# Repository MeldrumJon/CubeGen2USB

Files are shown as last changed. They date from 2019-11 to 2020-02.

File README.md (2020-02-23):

# CubeGen2USB

GameCube and Sega Genesis to USB adapter.  Works for both XInput and DInput 
(depending on which Arduino sketch is used). Only one controller may be used at 
a time (if both controllers are plugged in, the GameCube controller is used).

Photo of the adapter

## Parts

- Arduino Micro
- 1x [DB9 Male Connector](https://www.mouser.com/ProductDetail/571-2301843-1)
- 1x GameCube controller extension cable, cut in half with wires stripped.
- 5x [SPDT Slide Switches](https://www.amazon.com/gp/product/B01M1CU2B0/)
- 1x [Bi-Direction 3.3V-5V Logic Level Converter Module](https://www.amazon.com/gp/product/B07F7W91LC/)
	- or 1x BSS138 MOSFET and 2x 10k resistors.
- Breakaway Headers

Be careful when soldering the GameCube extension cable wires onto the PCB.  Use 
[this](https://github.com/NicoHood/Nintendo/wiki/Gamecube#hardware) as a reference, 
but disregard the wire colors.  Use a continuity tester to determine which wire 
is connected to each pin.

## PCB

KiCAD files are in the [hardware](./hardware) folder.

Circuit Schematic

3rd-party KiCAD libaries used:

- [Arduino KiCAD Library](https://github.com/Alarm-Siren/arduino-kicad-library)

## Programming

### DInput Setup

#### Required Libraries

- [SegaController by Jon Thysell](https://github.com/jonthysell/SegaController)
- Nintendo by NicoHood
- HID-Project by NicoHood

### XInput Setup

#### Hardware Setup

1. Download
[XInput USB Core for Arduino AVR](https://github.com/dmadison/ArduinoXInput_AVR) 
and extract it to `Arduino/hardware/xinput/avr`.
1. Change the board in Arduino IDE to "Arduino Micro w/ XInput".
1. Burn the bootloader using an In-circuit Serial Programmer ([Another Arduino 
can be used as an ISP](https://www.arduino.cc/en/tutorial/arduinoISP)).

Once the bootloader is burned, you will have to press the reset button when 
uploading sketches or simply upload using the ISP.

#### Required Libraries

- [SegaController by Jon Thysell](https://github.com/jonthysell/SegaController)
- Nintendo by NicoHood
- XInput by David Madison

## Features

The five switches can be used to control how buttons are mapped to the emulated 
XBox 360 controller. By default:

| XBox | GameCube | Genesis |
| --- | --- | --- |
| Start | Start | Start |
| A | A | A |
| B | B | B |
| X | X | X |
| Y | Y | Y |
| L Bumper | L Trigger Button | C |
| R Bumper | R Trigger Button | Mode |

- SW1: Swap A&B, X&Y
- SW2: Z maps to R Bumper
- SW3: 
- SW4: 
- SW5:

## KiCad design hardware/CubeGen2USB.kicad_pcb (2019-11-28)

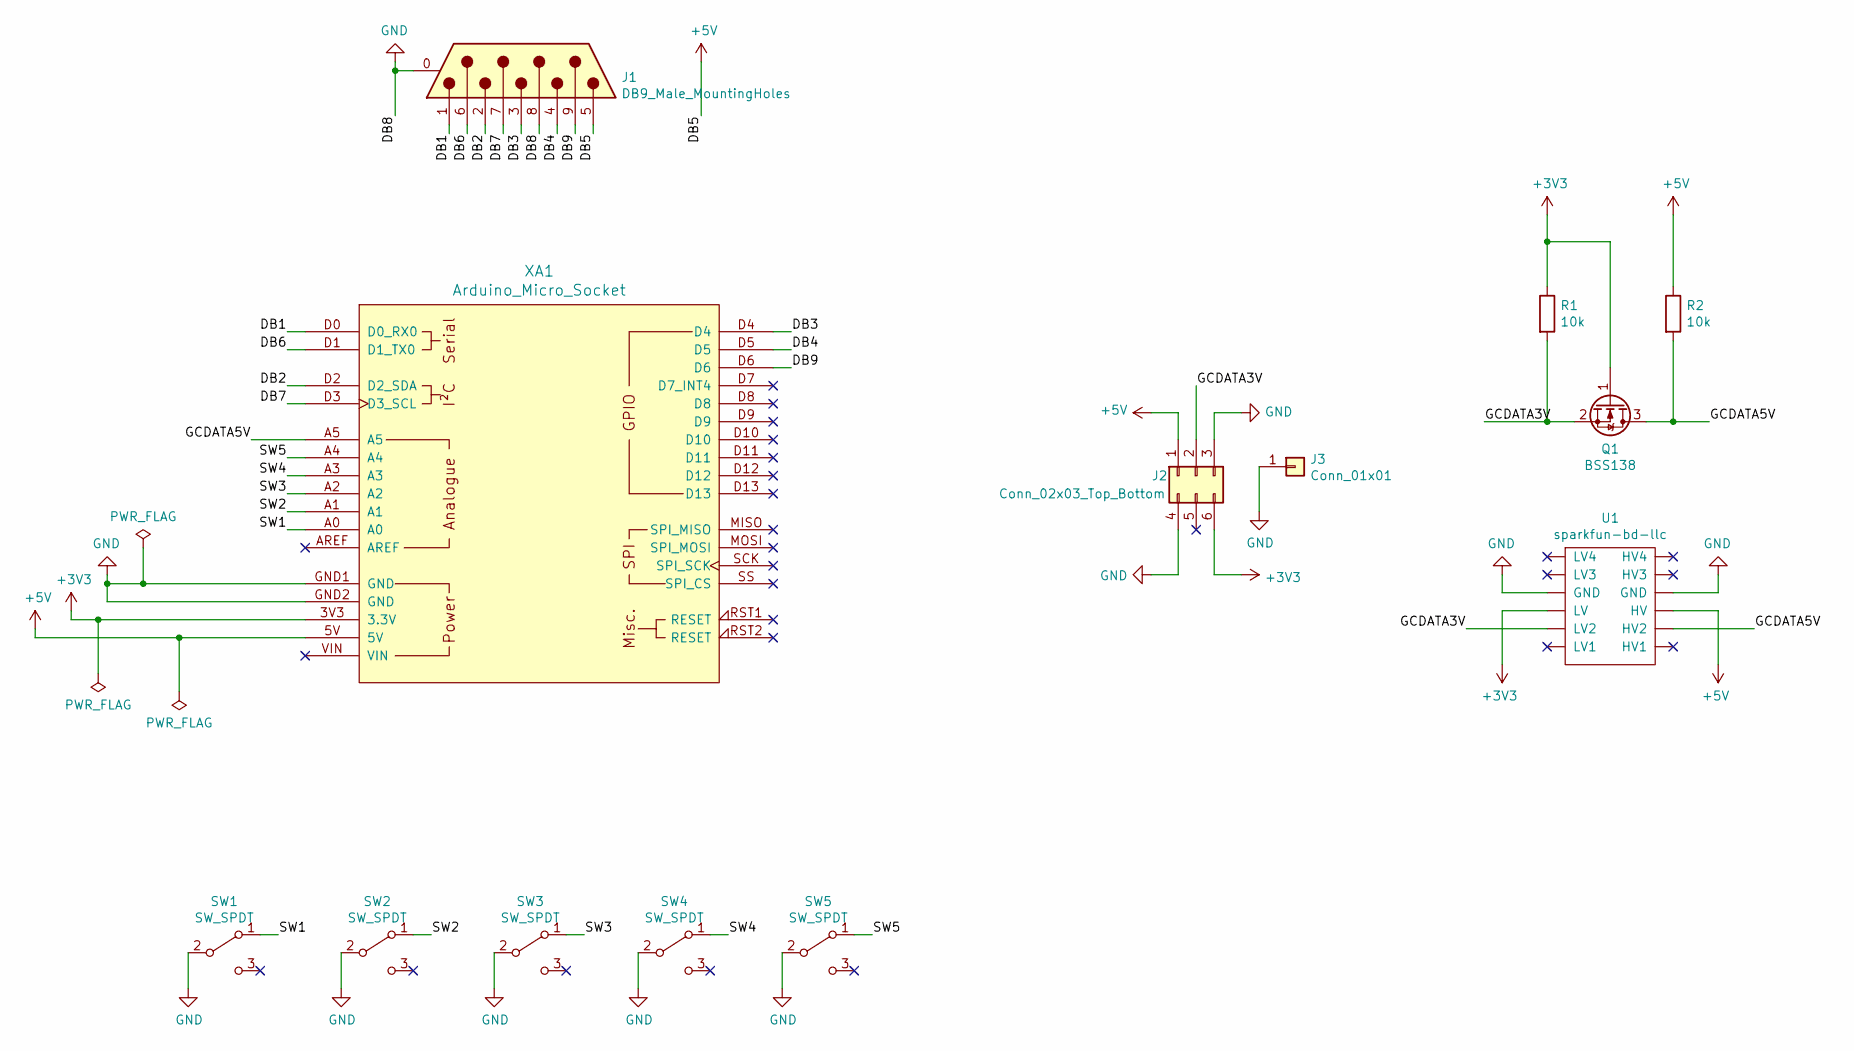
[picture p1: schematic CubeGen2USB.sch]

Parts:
J1: DB9_Male_MountingHoles; DB9-2301843-1
J2: Conn_02x03_Top_Bottom; PinSocket_2x03_P2.54mm_Vertical
J3: Conn_01x01; PinSocket_1x01_P2.54mm_Vertical
Q1: BSS138; SOT-23_Handsoldering
R1, R2: 10k; R_Axial_DIN0207_L6.3mm_D2.5mm_P2.54mm_Vertical
SW1, SW2, SW3, SW4, SW5: SW_SPDT; SPDT_THT_Slide_SW
U1: sparkfun-bd-llc
XA1: Arduino_Micro_Socket; Arduino_Micro_Socket_noHoles

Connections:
+3V3: J2.6, Q1.1 (G), R1.1, U1.LV, XA1.3V3 (3.3V)
+5V: J1.5, J2.1, R2.1, U1.HV, XA1.5V
/DB1: J1.1, XA1.D0 (D0_RX0)
/DB2: J1.2, XA1.D2 (D2_SDA)
/DB3: J1.3, XA1.D4
/DB4: J1.4, XA1.D5
/DB6: J1.6, XA1.D1 (D1_TX0)
/DB7: J1.7, XA1.D3 (D3_SCL)
/DB9: J1.9, XA1.D6
/GCDATA3V: J2.2, Q1.2 (S), R1.2, U1.LV2
/GCDATA5V: Q1.3 (D), R2.2, U1.HV2, XA1.A5
/SW1: SW1.1 (A), XA1.A0
/SW2: SW2.1 (A), XA1.A1
/SW3: SW3.1 (A), XA1.A2
/SW4: SW4.1 (A), XA1.A3
/SW5: SW5.1 (A), XA1.A4
GND: J1.0 (PAD), J1.8, J2.3, J2.4, J3.1, SW1.2 (B), SW2.2 (B), SW3.2 (B), SW4.2 (B), SW5.2 (B), U1.GNDH (GND), U1.GNDL (GND), XA1.GND1 (GND), XA1.GND2 (GND)

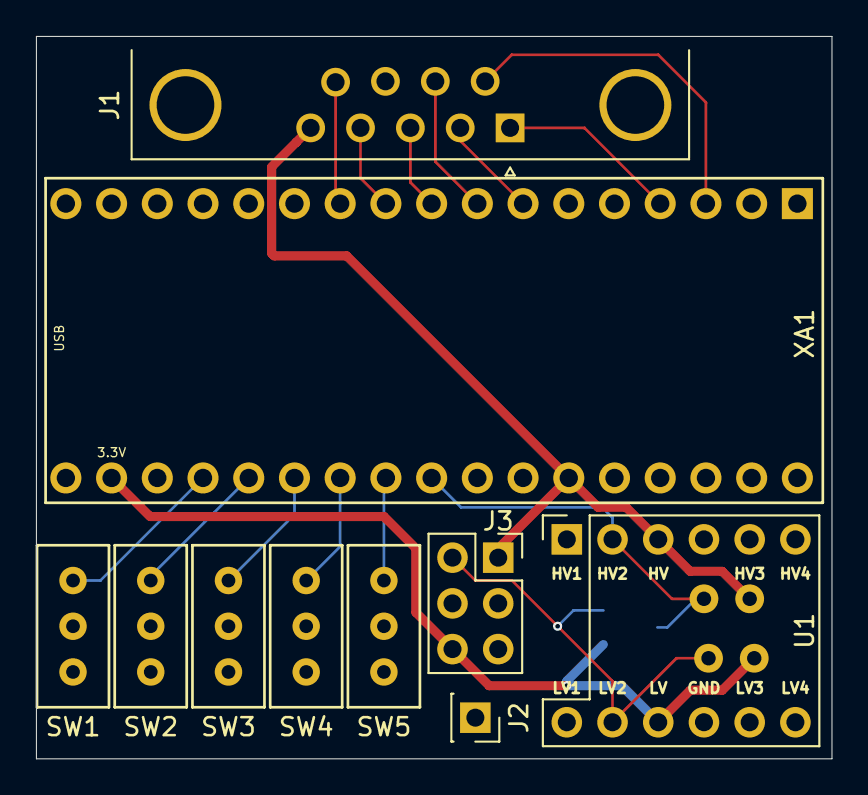
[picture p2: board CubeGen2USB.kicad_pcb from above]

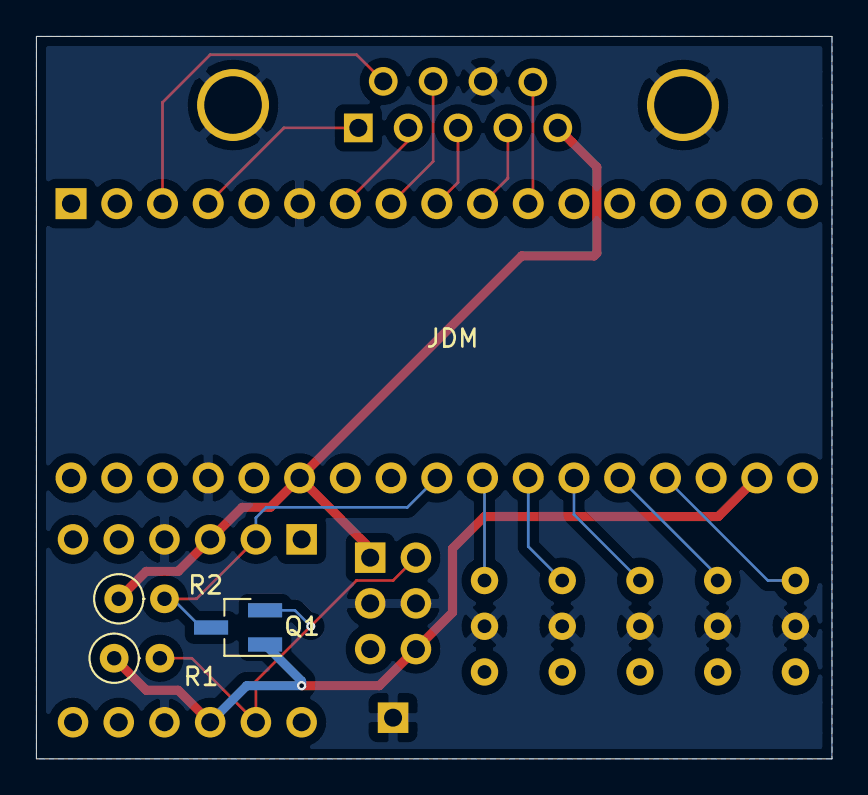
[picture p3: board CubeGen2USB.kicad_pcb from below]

Board: 2 copper layers, 44.2 x 40.1 mm, 13 parts (3 on the bottom side), 17 nets.

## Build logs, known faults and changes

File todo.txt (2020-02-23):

- Find a way to toggle between XInput and DInput with a switch.

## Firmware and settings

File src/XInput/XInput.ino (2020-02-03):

#include <SegaController.h>
#include <Nintendo.h>
#include <XInput.h>

// Micro Pins: 3, 0, 2, 4, 5, 1, 6 
// DB9 Pins:   7, 1, 2, 3, 4, 6, 9
SegaController sgController(3, 0, 2, 4, 5, 1, 6);
CGamecubeController gcController(A5); // 5V GC Data

#define SW1 0x01
#define SW2 0x02
#define SW3 0x04
#define SW4 0x08
#define SW5 0x10

static int readSwitches() {
    int val = 0;
    if (digitalRead(A0)) { val |= SW1; }
    if (digitalRead(A1)) { val |= SW2; }
    if (digitalRead(A2)) { val |= SW3; }
    if (digitalRead(A3)) { val |= SW4; }
    if (digitalRead(A4)) { val |= SW5; }
    return ~(val);
}

static int switches = 0;

static void sendGen(word state) {
  static word lastWrite = 0;
  if (state != lastWrite) {
    XInput.setDpad(
      state & SC_BTN_UP,
      state & SC_BTN_DOWN,
      state & SC_BTN_LEFT,
      state & SC_BTN_RIGHT
    );
    XInput.setButton(BUTTON_START, state & SC_BTN_START);
    if (switches & SW1) { // swap a&b, x&y
      XInput.setButton(BUTTON_B, state & SC_BTN_A);
      XInput.setButton(BUTTON_A, state & SC_BTN_B);
      XInput.setButton(BUTTON_Y, state & SC_BTN_X);
      XInput.setButton(BUTTON_X, state & SC_BTN_Y);
    }
    else {
      XInput.setButton(BUTTON_A, state & SC_BTN_A);
      XInput.setButton(BUTTON_B, state & SC_BTN_B);
      XInput.setButton(BUTTON_X, state & SC_BTN_X);
      XInput.setButton(BUTTON_Y, state & SC_BTN_Y);
    }
    XInput.setButton(BUTTON_LB, state & SC_BTN_C);
    if (switches & SW2) { // z imitates right bumper
      XInput.setButton(BUTTON_RB, state & SC_BTN_Z);
    }
    else {
      XInput.setButton(BUTTON_RB, state & SC_BTN_MODE);
    }

    lastWrite = state;
    XInput.send();
  }
}

void sendGC(Gamecube_Report_t &report, bool rumble=false) {
  static Gamecube_Report_t lastReport;
  static bool lastRumble;
  static unsigned long nextAxisUpdate = 0;
  bool doWrite = false;

  unsigned long t = millis();
  if (t > nextAxisUpdate) { // Send axis data every few ms
    XInput.setJoystickX(JOY_LEFT, (int32_t) (report.xAxis - 0x80));
    XInput.setJoystickY(JOY_LEFT, (int32_t) (report.yAxis - 0x80));
    XInput.setJoystickX(JOY_RIGHT, (int32_t) (report.cxAxis - 0x80));
    XInput.setJoystickY(JOY_RIGHT, (int32_t) ~(report.cyAxis - 0x80));
    XInput.setTrigger(TRIGGER_LEFT, (int32_t) (report.left - 0x80));
    XInput.setTrigger(TRIGGER_RIGHT, (int32_t) (report.right - 0x80));
    nextAxisUpdate = t + 3; // every 3ms
    doWrite = true;
  }

  if (report.buttons0 != lastReport.buttons0 
      || report.buttons1 != lastReport.buttons1) {
    XInput.setDpad(report.dup, report.ddown, report.dleft, report.dright);
    XInput.setButton(BUTTON_START, report.start);
    if (switches & SW1) { // swap a&b, x&y
      XInput.setButton(BUTTON_B, report.a);
      XInput.setButton(BUTTON_A, report.b);
      XInput.setButton(BUTTON_Y, report.x);
      XInput.setButton(BUTTON_X, report.y);
    }
    else {
      XInput.setButton(BUTTON_A, report.a);
      XInput.setButton(BUTTON_B, report.b);
      XInput.setButton(BUTTON_X, report.x);
      XInput.setButton(BUTTON_Y, report.y);
    }
    if (switches & SW2) { // use z for bumper instead of L&R buttons
      XInput.setButton(BUTTON_RB, report.z);
    }
    else {
      XInput.setButton(BUTTON_LB, report.l);
      XInput.setButton(BUTTON_RB, report.r);
    }
    doWrite = true;
  }

  if (doWrite) { XInput.send(); }

  if (lastRumble != rumble) {
    gcController.setRumble(rumble);
  }
  
  lastReport = report;
  lastRumble = rumble;
}

void setup() {
  // Controller indicator
  pinMode(LED_BUILTIN, OUTPUT);
  // Switches
  pinMode(A0, INPUT_PULLUP);
  pinMode(A1, INPUT_PULLUP);
  pinMode(A2, INPUT_PULLUP);
  pinMode(A3, INPUT_PULLUP);
  pinMode(A4, INPUT_PULLUP);
  // Gamecube joystick range
  XInput.setTriggerRange(-128, 127);
  XInput.setRange(JOY_LEFT, -128, 127);
  XInput.setRange(JOY_RIGHT, -128, 127);
  // Wait for all controls before sending
  XInput.setAutoSend(false);

  XInput.begin();
}

void loop() {
  switches = readSwitches();

  if (gcController.read()) {
    digitalWrite(LED_BUILTIN, HIGH); // Controller plugged in
    Gamecube_Report_t report = gcController.getReport();
    sendGC(report, (XInput.getRumble() > 15)); // only rumble with when XBox's large motor should rumble.
    return;
  }
  word state = sgController.getState();
  if (state & SC_CTL_ON) { // Controller plugged in
    digitalWrite(LED_BUILTIN, HIGH);
    sendGen(state);
    delay(10);
    return;
  }
  // No controller
  digitalWrite(LED_BUILTIN, LOW);
  XInput.releaseAll();
  XInput.send();
  delay(500); // Try again in half a second
}

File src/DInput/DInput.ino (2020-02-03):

#include <SegaController.h>
#include <Nintendo.h>
#include <HID-Project.h>

// Micro Pins: 3, 0, 2, 4, 5, 1, 6 
// DB9 Pins:   7, 1, 2, 3, 4, 6, 9
SegaController sgController(3, 0, 2, 4, 5, 1, 6);
CGamecubeController gcController(A5); // 5V GC Data

// dPad -> HID dPad
static int8_t dPadDir(bool up, bool down, bool left, bool right) {
  if (up && right) { return GAMEPAD_DPAD_UP_RIGHT; }
  else if (up && left) { return GAMEPAD_DPAD_UP_LEFT; }
  else if (down && right)  { return GAMEPAD_DPAD_DOWN_RIGHT; }
  else if (down && left) { return GAMEPAD_DPAD_DOWN_LEFT; }
  else if (up) { return GAMEPAD_DPAD_UP; }
  else if (right) { return GAMEPAD_DPAD_RIGHT; }
  else if (down) { return GAMEPAD_DPAD_DOWN; }
  else if (left)  { return GAMEPAD_DPAD_LEFT; }
  else { return GAMEPAD_DPAD_CENTERED; }
}

static void sendGen(word state) {
  static word lastWrite = 0;
  if (state != lastWrite) {
    Gamepad.dPad1(
      dPadDir(
        state & SC_BTN_UP,
        state & SC_BTN_DOWN,
        state & SC_BTN_LEFT,
        state & SC_BTN_RIGHT
      )
    );
    Gamepad.buttons(0x00UL | state >> 5);

    lastWrite = state;
    Gamepad.write();
  }
}

void sendGC(Gamecube_Report_t &report)
{
  // The two control sticks
  Gamepad.xAxis((report.xAxis - 0x80) << 8);
  Gamepad.yAxis(~(report.yAxis - 0x80) << 8); // y stick needs to be inverted
  Gamepad.rxAxis((report.cxAxis - 0x80) << 8);
  Gamepad.ryAxis((report.cyAxis - 0x80) << 8);
  // you can merge L/R (PS3 controller uses this methode too)
  // or you can also seperate the triggers
  // for Windows calibration comment out the l/r buttons below
  // (because l/r triggers the wizard)
  //Gamepad.zAxis(abs(gc_report.left - gc_report.right) - 0x80);
  Gamepad.zAxis(report.left - 0x80);
  Gamepad.rzAxis(report.right - 0x80);

  Gamepad.dPad1(
    dPadDir(
      report.dup,
      report.ddown,
      report.dleft,
      report.dright
    )
  );
  // 8 Gamecube buttons
  Gamepad.buttons(0x00UL | (report.buttons0 & 0x1F) | ((report.buttons1 & 0x70) << 1));

  Gamepad.write();
}

void setup() {
  pinMode(LED_BUILTIN, OUTPUT);
  Gamepad.begin();
}

void loop() {
  if (gcController.read()) {
    digitalWrite(LED_BUILTIN, HIGH); // Controller plugged in
    Gamecube_Report_t report = gcController.getReport();
    sendGC(report);
    delay(20);
    return;
  }
  word state = sgController.getState();
  if (state & SC_CTL_ON) { // Controller plugged in
    digitalWrite(LED_BUILTIN, HIGH);
    sendGen(state);
    delay(10);
    return;
  }

  // No controller
  digitalWrite(LED_BUILTIN, LOW);
  Gamepad.releaseAll();
  Gamepad.write();
  delay(500); // Try again in half a second
}

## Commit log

2019-11-28 PCB, Sketches
    [CubeGen2USB.kicad_pcb, CubeGen2USB.sch]
2019-11-28 Small silkscreen update
    [CubeGen2USB.kicad_pcb]
